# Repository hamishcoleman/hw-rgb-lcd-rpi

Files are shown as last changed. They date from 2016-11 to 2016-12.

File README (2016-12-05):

This design is to adapt a "raw" or "dotclock" LCD to the Raspberry-Pi
expansion pinout, and allow it to be connected directly to the GPU
(not via SPI)

TODO:
- clarify the OSHW licence
- Add more documentation
- The lq043t1dg03 footprint needs adjusting - the large mechanical stay
  pads are in the wrong places
- All the custom footprints need a pin 1 indicator

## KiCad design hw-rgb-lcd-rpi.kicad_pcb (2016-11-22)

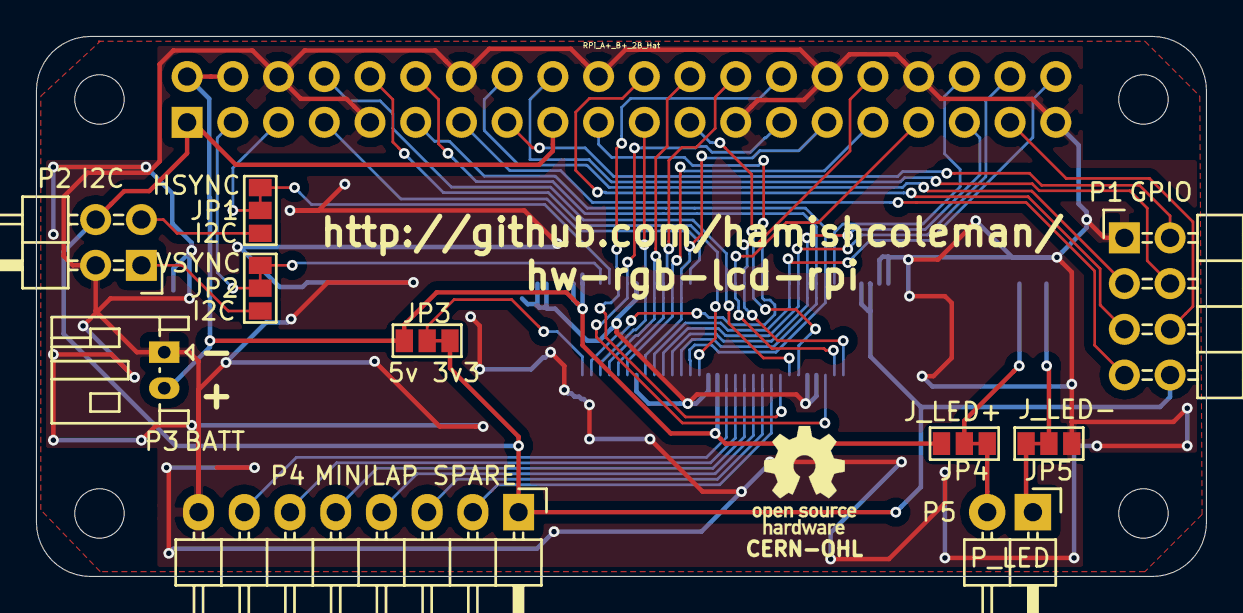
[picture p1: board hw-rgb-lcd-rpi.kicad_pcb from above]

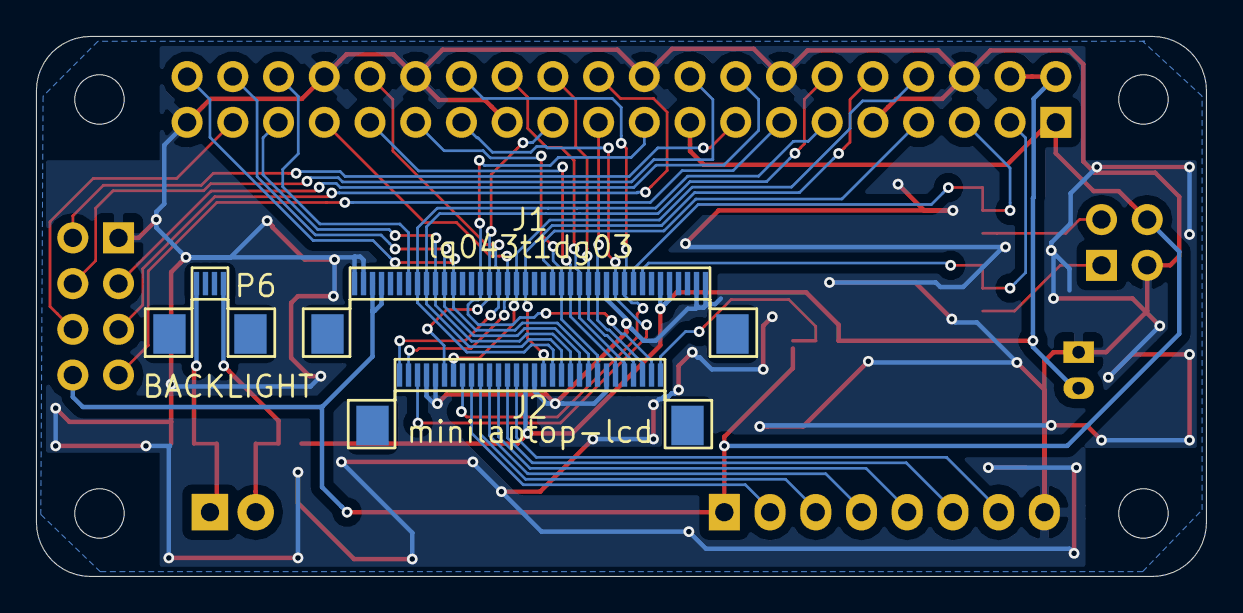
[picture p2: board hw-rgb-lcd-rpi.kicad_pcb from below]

Board: 2 copper layers, 65.0 x 30.0 mm, 14 parts (3 on the bottom side), 42 nets.

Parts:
J1: lq043t1dg03; FPC_40
J2: minilaptop-lcd; FPC_30
JP1: HSYNC; GS3
JP2: VSYNC; GS3
JP3: 5v 3v3; GS3
JP4: J_LED+; GS3
JP5: J_LED-; GS3
P1: GPIO; Pin_Header_Angled_2x04
P2: I2C; Pin_Header_Angled_2x02
P3: BATT; JST_PH_S2B-PH-K_02x2.00mm_Angled
P4: MINILAP SPARE; Pin_Header_Angled_1x08
P5: P_LED; Pin_Header_Angled_1x02
P6: BACKLIGHT; FPC_4
U1: RPi_A+_B+_2B_Hat; z_RPiZero_Hat_NPTH

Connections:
+BATT: J1.35, J1.36, J2.15, JP3.1, JP4.3, P3.2, U1.2, U1.4
/B2: J1.23, U1.7
/B3: J1.24, J2.23, U1.29
/B4: J1.25, J2.25, U1.31
/B5: J1.26, J2.26, U1.26
/B6: J1.27, J2.27, U1.24
/B7: J1.28, J2.28, U1.21
/DEN: J1.31, J2.8, U1.28
/DOTCLK: J1.30, J2.3, U1.27
/G2: J1.15, J2.29, U1.19
/G3: J1.16, J2.6, U1.23
/G4: J1.17, J2.1, U1.32
/G5: J1.18, J2.2, U1.33
/G6: J1.19, J2.7, U1.8
/G7: J1.20, J2.17, U1.10
/GPIO22: P1.2, U1.15
/GPIO23: P1.3, U1.16
/GPIO24: P1.4, U1.18
/GPIO25: P1.5, U1.22
/GPIO26: P1.6, U1.37
/GPIO27: P1.7, U1.13
/H_SYNC: J1.32, JP1.2, JP1.3, U1.5
/R2: J1.7, U1.36
/R3: J1.8, J2.18, U1.11
/R4: J1.9, J2.19, U1.12
/R5: J1.10, J2.20, U1.35
/R6: J1.11, J2.21, U1.38
/R7: J1.12, J2.22, U1.40
/SCL: JP1.1, P2.3
/SDA: JP2.3, P2.1
/V_SYNC: J1.33, JP2.1, JP2.2, U1.3
GND: J1.1, J1.2, J1.29, J1.39, J1.40, J2.4, J2.5, J2.16, J2.24, JP5.1, P1.1, P2.2, P3.1, P4.8, U1.6, U1.9, U1.14, U1.20, U1.25, U1.30, U1.34, U1.39
unnamed: J2.9, P4.2
unnamed: J2.10, P4.3
unnamed: J2.11, P4.4
unnamed: J2.12, P4.5
unnamed: J2.13, P4.6
unnamed: J2.14, P4.7
unnamed: J2.30, JP3.2
unnamed: JP4.1, JP4.2, P5.2, P6.4
unnamed: JP5.2, JP5.3, P5.1, P6.1
VCC: J1.3, J1.4, JP3.3, P1.8, P2.4, P4.1, U1.1, U1.17

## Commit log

2016-11-10 Create empty kicad project
    [hw-rgb-lcd-rpi.kicad_pcb, hw-rgb-lcd-rpi.sch]
2016-11-10 Import Raspberry Pi libraries from kicad forum: https://forum.kicad.info/t/raspberry-pi-b-hat-template/738/35
2016-11-10 Add new parts for the two LCD connectors
    [hw-rgb-lcd-rpi.sch]
2016-11-10 Add bus wires
    [hw-rgb-lcd-rpi.sch]
2016-11-11 Label and allow connections to the HAT I2C pins
2016-11-11 All pins wired up
    [hw-rgb-lcd-rpi.sch]
2016-11-11 Add missing backlight connector
    [hw-rgb-lcd-rpi.sch]
2016-11-11 Add most footprints
    [hw-rgb-lcd-rpi.sch]
2016-11-11 Add some footprints for the FPC connectors
    [hw-rgb-lcd-rpi.sch]
2016-11-11 Add backlight FPC, adjust headers to be smaller
    [hw-rgb-lcd-rpi.sch]
2016-11-11 Ignore pcb backups
2016-11-11 Initial trial placement of all parts
    [hw-rgb-lcd-rpi.kicad_pcb]
2016-11-11 Set design rules as per hackvana
    [hw-rgb-lcd-rpi.kicad_pcb]
2016-11-11 Make power tracks visibly wider
    [hw-rgb-lcd-rpi.kicad_pcb]
2016-11-11 minilaptop power supply should select between powered by VCC or VBATT - fix
    [hw-rgb-lcd-rpi.sch]
2016-11-11 Rearrange I2C pins for simpler layout
    [hw-rgb-lcd-rpi.sch]
2016-11-11 Switch more pins to make layout simpler
    [hw-rgb-lcd-rpi.sch]
2016-11-11 All tracks routed, however the layout is sub-optimal
    [hw-rgb-lcd-rpi.kicad_pcb]
2016-11-11 Rearrange the mini-laptop spare pins to make routing simple
    [hw-rgb-lcd-rpi.kicad_pcb, hw-rgb-lcd-rpi.sch]
2016-11-11 Clean up routing
    [hw-rgb-lcd-rpi.kicad_pcb, hw-rgb-lcd-rpi.sch]
2016-11-11 Minor label adjustments
    [hw-rgb-lcd-rpi.kicad_pcb]
2016-11-11 Add GND fill
    [hw-rgb-lcd-rpi.kicad_pcb]
2016-11-11 Ensure keepout areas and edge cuts are marked
    [hw-rgb-lcd-rpi.kicad_pcb]
2016-11-11 Add labels and adjust silkscreen for all parts
    [hw-rgb-lcd-rpi.kicad_pcb]
2016-11-11 Save gerber settings to project
    [hw-rgb-lcd-rpi.kicad_pcb]
2016-11-11 Re-add fill regions
    [hw-rgb-lcd-rpi.kicad_pcb]
2016-11-11 Add dimension lines
    [hw-rgb-lcd-rpi.kicad_pcb]
2016-11-22 Add a licence name to the silkscreen
    [hw-rgb-lcd-rpi.kicad_pcb]
2016-11-22 update design rules for via sizes after talking to hackvana
    [hw-rgb-lcd-rpi.kicad_pcb]
2016-11-22 Minor track adjustment - two tracks didnt need to be so close
    [hw-rgb-lcd-rpi.kicad_pcb]
2016-11-22 Search and replace via drill sizes to match suggestions
    [hw-rgb-lcd-rpi.kicad_pcb]
2016-11-22 Use gerblook and friends to address copper layer wierdness
    [hw-rgb-lcd-rpi.kicad_pcb]
2016-11-22 Stitch the copper fills together where it seemed needed, more minor adjustments to remove warts
    [hw-rgb-lcd-rpi.kicad_pcb]
2016-12-05 Update TODO list with current items
2017-02-13 Add some simple automation to create the gerbers

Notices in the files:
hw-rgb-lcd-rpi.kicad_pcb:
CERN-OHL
